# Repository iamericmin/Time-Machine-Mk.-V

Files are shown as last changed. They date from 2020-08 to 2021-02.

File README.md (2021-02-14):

# Time Machine Mk. V
# [Full write-up is on my website! It's also got links to my hackaday page, imgur album, and more goodies. You won't regret it](https://iamericmin.github.io/tm5.html)
Peekaboo!
## DIY nRF52 watch with BLE

Project status: idk

# hi
This is an update of my previous project, the Time Machine Mk. IV. It's better than its predecessor in almost every way I can imagine. There are still some minor bugs and kinks but I am super satisfied with how it turned out. It's got a cyberpunk themed design and motorsport-inspired livery.

# THE JUICY STUFF:
-   PROCESSOR: nRF52832 Soc. 64MHz ARM cortex M4 with 64k RAM and 512k flash.
-   FIRMWARE: Espruino JS interpreter + JS code. I'm working on a C/C++ version.
-   POWER: CR2032 coin cell battery. Guesstimated battery life of around a month.
-   DISPLAY: Dual 7-segment LEDs with five auxiliary LEDs.
-   INPUT: Triple momentary tactile switches.
-   SOUND: Mini piezo speaker.
-   DIMENSIONS: 43.18mm width and length, 9.2mm thickness(1mm thinner than the Mark IV!).
-   STRAP: 22mm NATO strap.

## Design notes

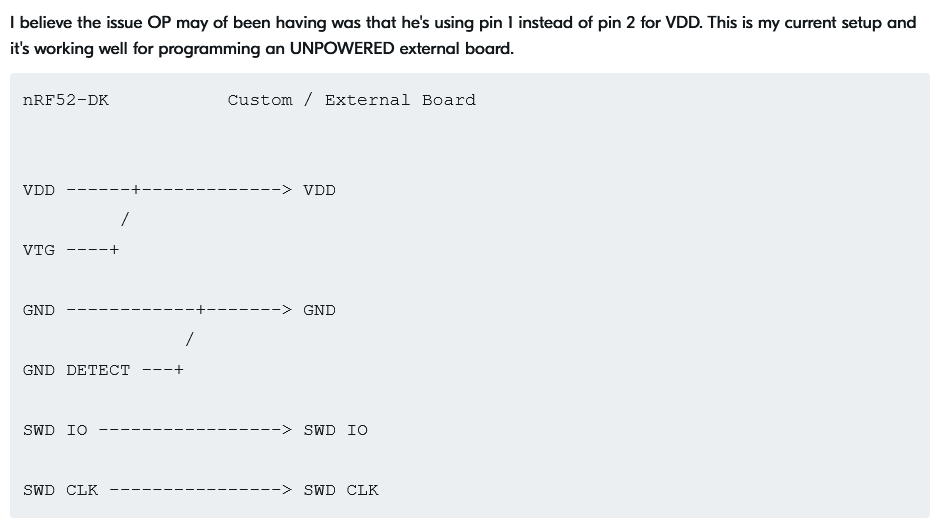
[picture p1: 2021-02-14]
hardware/tm5_swd_connection.png

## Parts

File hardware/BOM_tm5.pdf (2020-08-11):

Description | Quantity Digi-Key Part Number | Unit Price Extended Price Manufacturer
SWITCH TACTILE SPST-NO 0.05A 32V | 3 401-1766-1-ND | 0.49 $1.47 | C&K
LED BLUE CLEAR CHIP SMD | 5 160-1645-1-ND | 0.46 $2.30 | Lite-On Inc.
AUDIO MAGNETIC XDCR 2-4V SMD | 1 668-1060-1-ND | 3.03 $3.03 | PUI Audio, Inc.
RES SMD 220 OHM 1% 1/10W 0603 | 12 311-220HRCT-ND | 0.022 $0.26 | Yageo
CONN HEADER SMD R/A 8POS 1MM | 1 455-1808-1-ND | 0.9 $0.90 | JST Sales America Inc.
CAP CER 22PF 100V C0G/NP0 0603 | 2 399-7874-1-ND | 0.1 $0.20 | KEMET
CRYSTAL 32.7680 KHZ 12.5PF SMD | 1 SER4103CT-ND | 0.41 $0.41 | EPSON
BATTERY RETAINER COIN 20MM SMD | 1 36-3034CT-ND | 0.44 $0.44 | Keystone Electronics
DISPLAY 7SEG 0.28" SGL GRN 10SMD | 2 DSM7TA28105TCT-ND | 2.4 $4.80 | Visual Communications Company - VCC
RX TXRX MOD BLE CHIP SMD | 1 1597-1434-ND | 10.1 $10.10 | Seeed Technology Co., Ltd

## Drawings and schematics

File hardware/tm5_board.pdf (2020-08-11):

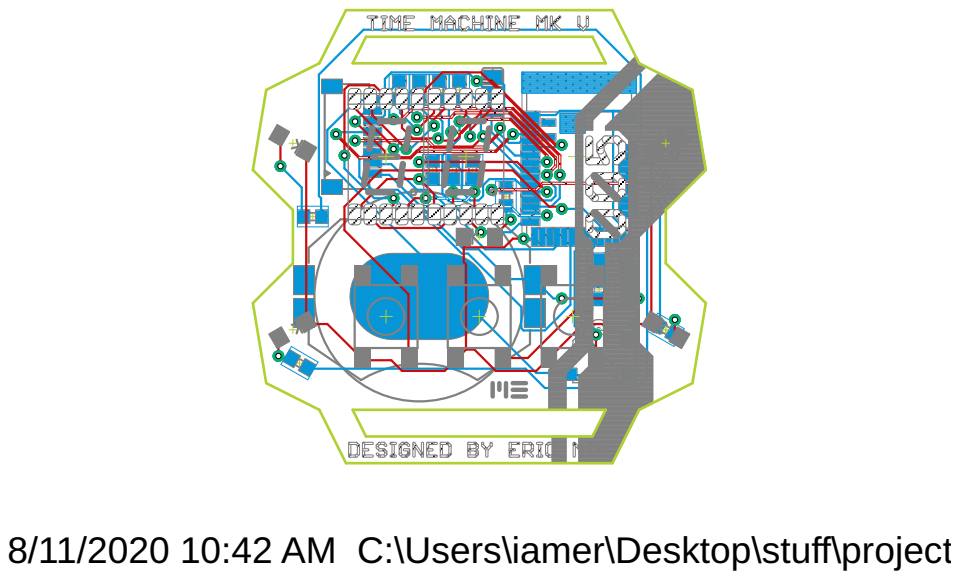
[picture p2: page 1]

8/11/2020 10:42 AM C:\Users\iamer\Desktop\stuff\project

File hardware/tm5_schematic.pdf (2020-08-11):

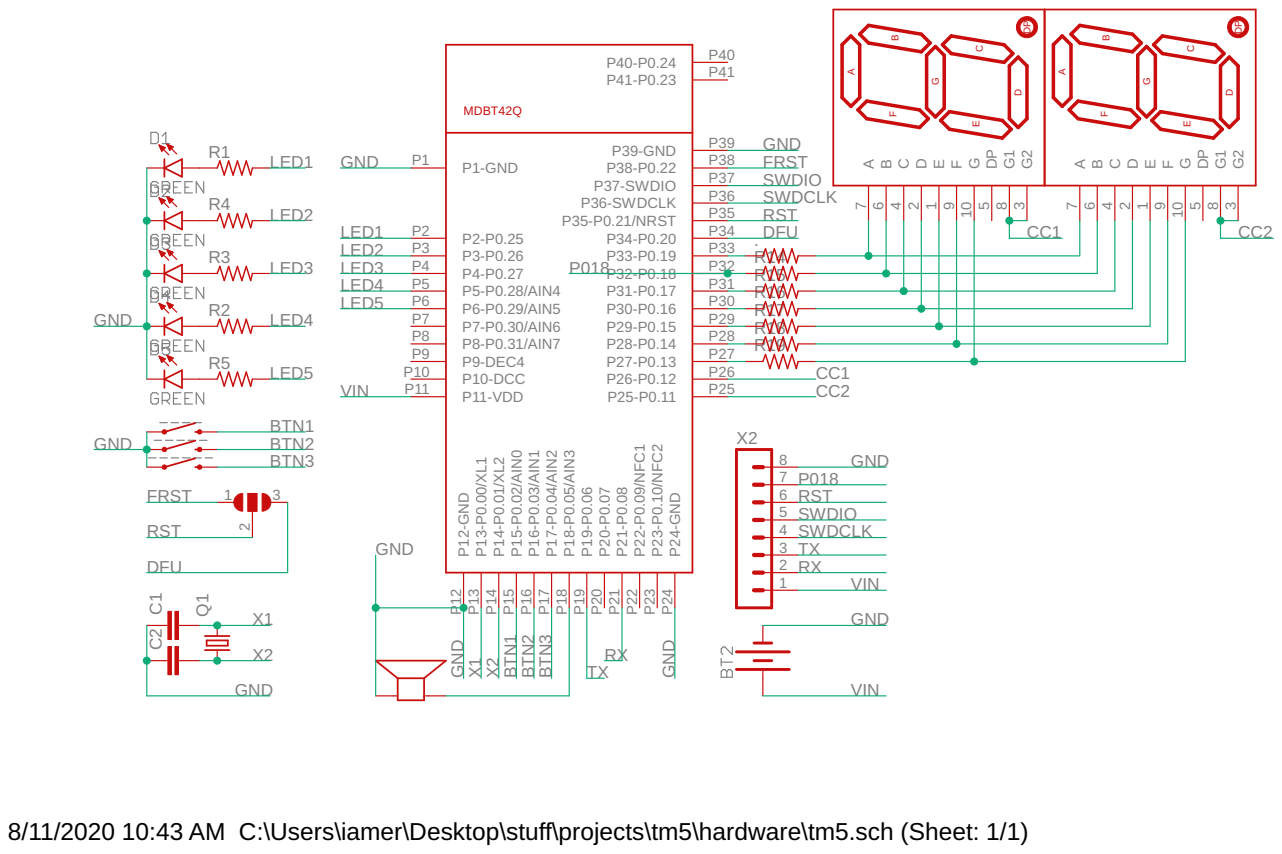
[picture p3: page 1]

8/11/2020 10:43 AM C:\Users\iamer\Desktop\stuff\projects\tm5\hardware\tm5.sch (Sheet: 1/1)

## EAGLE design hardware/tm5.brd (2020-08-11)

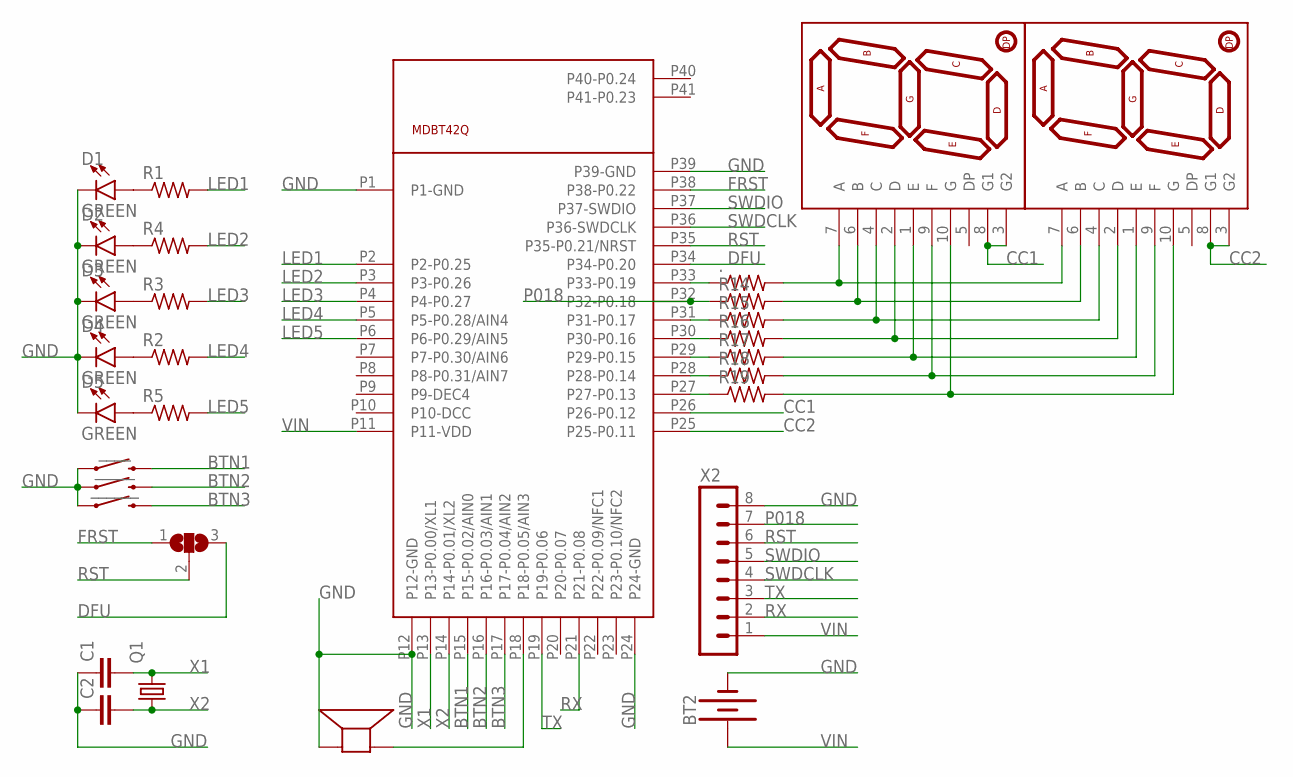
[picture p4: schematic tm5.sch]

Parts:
.: R-US_R0603; R0603
BT2: BATTERY-20MM_SMD_4LEGS_OVERPASTE; BATTCON_20MM_4LEGS_OVERPASTE
C1, C2: C-EUC0603; C0603
CFG: SJ2W; SJ_2
D1, D2, D3, D4, D5: GREEN; LED-1206
Q1: KX-327-NHT; 3.2X1.5
R1, R2, R3, R4, R5, R14, R15, R16, R17, R18, R19: R-US_R0603; R0603
SPK1: SMT-0540-S-R
U$1: MDBT42Q; MDBT40
U$2, U$3: 7-SEGMENT-DISPLAY-1"-RED; 7-SEGMENT-SMD
X2: SM08B-SRSS-TB
____: MOMENTARY-SWITCH-SPST-SMD-6.2MM-TALL; TACTILE_SWITCH_SMD_6.2MM_TALL
_____: MOMENTARY-SWITCH-SPST-SMD-6.2MM-TALL; TACTILE_SWITCH_SMD_6.2MM_TALL
______: MOMENTARY-SWITCH-SPST-SMD-6.2MM-TALL; TACTILE_SWITCH_SMD_6.2MM_TALL

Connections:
BTN1: U$1.P15 (P15-P0.02/AIN0), ____.B2 (2)
BTN2: U$1.P16 (P16-P0.03/AIN1), _____.B2 (2)
BTN3: U$1.P17 (P17-P0.04/AIN2), ______.B2 (2)
CC1: U$1.P26 (P26-P0.12), U$2.3 (G2), U$2.8 (G1)
CC2: U$1.P25 (P25-P0.11), U$3.3 (G2), U$3.8 (G1)
DFU: CFG.3, U$1.P34 (P34-P0.20)
FRST: CFG.1, U$1.P38 (P38-P0.22)
GND: BT2.2 (-), C1.1, C2.1, D1.C, D2.C, D3.C, D4.C, D5.C, SPK1.- (+), U$1.P1 (P1-GND), U$1.P12 (P12-GND), U$1.P24 (P24-GND), U$1.P39 (P39-GND), X2.8, ____.A2 (1), _____.A2 (1), ______.A2 (1)
LED1: R1.2, U$1.P2 (P2-P0.25)
LED2: R4.2, U$1.P3 (P3-P0.26)
LED3: R3.2, U$1.P4 (P4-P0.27)
LED4: R2.2, U$1.P5 (P5-P0.28/AIN4)
LED5: R5.2, U$1.P6 (P6-P0.29/AIN5)
unnamed: ..1, U$1.P33 (P33-P0.19)
unnamed: R15.1, U$1.P31 (P31-P0.17)
unnamed: D1.A, R1.1
unnamed: D2.A, R4.1
unnamed: D3.A, R3.1
unnamed: D4.A, R2.1
unnamed: R16.1, U$1.P30 (P30-P0.16)
unnamed: R17.1, U$1.P29 (P29-P0.15)
unnamed: R18.1, U$1.P28 (P28-P0.14)
unnamed: R19.1, U$1.P27 (P27-P0.13)
unnamed: ..2, U$2.7 (A), U$3.7 (A)
unnamed: SPK1.+ (-), U$1.P18 (P18-P0.05/AIN3)
unnamed: R14.2, U$2.6 (B), U$3.6 (B)
unnamed: R15.2, U$2.4 (C), U$3.4 (C)
unnamed: D5.A, R5.1
unnamed: R16.2, U$2.2 (D), U$3.2 (D)
unnamed: R17.2, U$2.1 (E), U$3.1 (E)
unnamed: R18.2, U$2.9 (F), U$3.9 (F)
unnamed: R19.2, U$2.10 (G), U$3.10 (G)
P018: R14.1, U$1.P32 (P32-P0.18), X2.7
RST: CFG.2, U$1.P35 (P35-P0.21/NRST), X2.6
RX: U$1.P21 (P21-P0.08), X2.2
SWDCLK: U$1.P36 (P36-SWDCLK), X2.4
SWDIO: U$1.P37 (P37-SWDIO), X2.5
TX: U$1.P19 (P19-P0.06), X2.3
VIN: BT2.1 (+), U$1.P11 (P11-VDD), X2.1
X1: C1.2, Q1.2, U$1.P13 (P13-P0.00/XL1)
X2: C2.2, Q1.1, U$1.P14 (P14-P0.01/XL2)

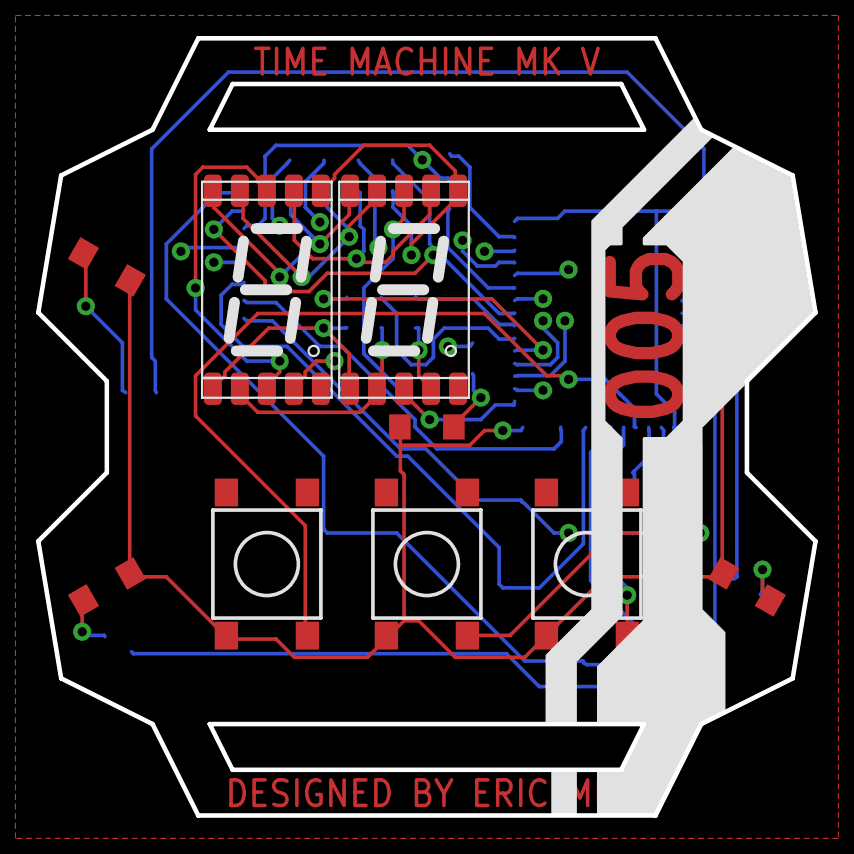
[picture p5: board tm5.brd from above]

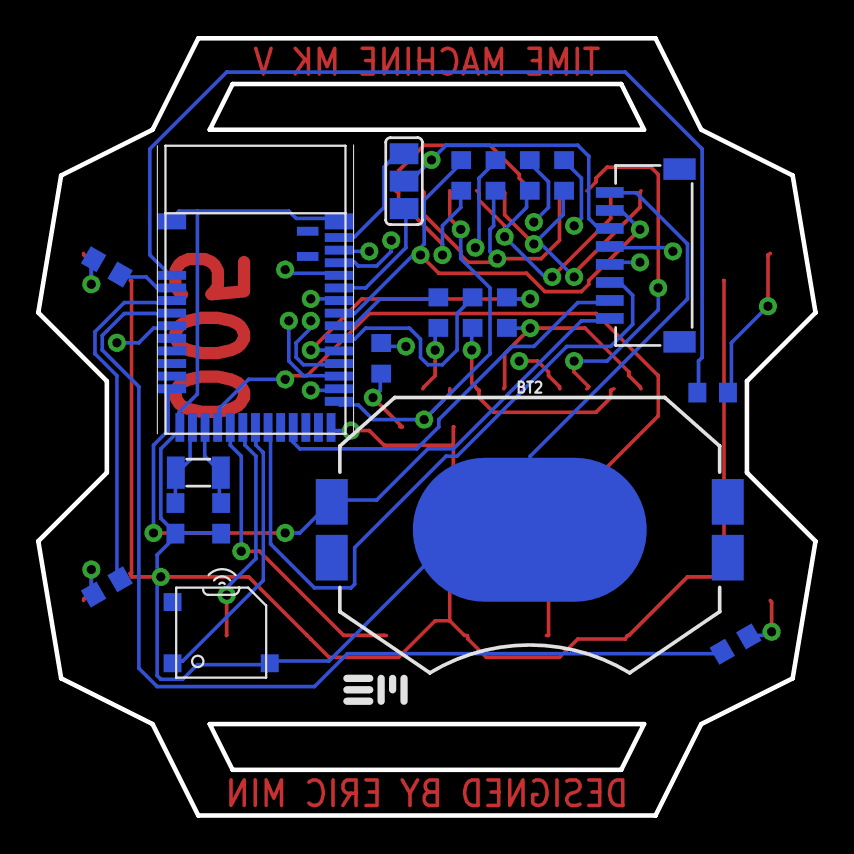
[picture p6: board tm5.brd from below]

Board: 4 copper layers, 43.2 x 43.2 mm, 30 parts (20 on the bottom side), 41 nets.

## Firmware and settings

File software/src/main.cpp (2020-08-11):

/*
 ______   __     __    __     ______        ______     ______   ______   ______     ______     __  __    
/\__  _\ /\ \   /\ "-./  \   /\  ___\      /\  __ \   /\__  _\ /\__  _\ /\  __ \   /\  ___\   /\ \/ /    
\/_/\ \/ \ \ \  \ \ \-./\ \  \ \  __\      \ \  __ \  \/_/\ \/ \/_/\ \/ \ \  __ \  \ \ \____  \ \  _"-.  
   \ \_\  \ \_\  \ \_\ \ \_\  \ \_____\     \ \_\ \_\    \ \_\    \ \_\  \ \_\ \_\  \ \_____\  \ \_\ \_\ 
    \/_/   \/_/   \/_/  \/_/   \/_____/      \/_/\/_/     \/_/     \/_/   \/_/\/_/   \/_____/   \/_/\/_/ 
2020 Eric Min

*/

#include <Arduino.h>

int dg1 = 12;
int dg2 = 11;
int A = 19;
int B = 18;
int C = 17;
int D = 16;
int E = 15;
int F = 14;
int G = 13;
int l1 = 25;
int l2 = 26;
int l3 = 27;
int l4 = 28;
int l5 = 29;
int left = 0;
int slct = 1;
int right = 2;
int spk = 5;

/*
A little help?
            ----A----
            |       |
            F       B
            |       |
            ----G----
            |       |
            E       C
            |       |
            ----D----
*/

int seg[7] = {A, B, C, D, E, F};
int leds[12] = {A, B, C, D, E, F, l1, l2, l3, l4, l5};

int one[8] = {F, E};
int two[8] = {A, B, G, E, D};
int three[8] = {A, B, G, C, D};
int four[8] = {F, G, B, C};
int five[8] = {A, F, G, C, D};
int six[8] = {A, F, E, D, C, G};
int seven[8] = {F, A, B, C};
int eight[8] = {A, B, C, D, E, F, G};
int nine[8] = {F, A, B, G, C, D};
int zero[8] = {A, B, C, D, E, F};
int aa[8] = {E, F, A, B, C ,G};
int bb[8] = {F, E, D, C ,G};
int cc[8] = {A, F, E, D};
int dd[8] = {B, C, D, E, G};
int ee[8] = {A, F, G, E, D};
int ff[8] = {A, F, G, E};

void write(int ledBuffer[8]) {
  for (int i=0; i<8; i++) {
    digitalWrite(ledBuffer[i], 1);
  }
}

void unWrite(int ledBuffer[8]) {
  for (int i=0; i<8; i++) {
    digitalWrite(ledBuffer[i], 0);
  }
}

void allClear() {
	digitalWrite(dg1, 1);
	digitalWrite(dg2, 1);
	for (unsigned int i=0; i<sizeof(leds); i++) {
		digitalWrite(leds[i], 0);
	}
}

void clearDigits() {
	for (unsigned int i=0; i<sizeof(seg); i++) {
		digitalWrite(seg[i], 0);
	}
}

void display(int digit, int buf[8]) {
  allClear();
  if (digit == 1) {
    digitalWrite(dg1, 0);
    digitalWrite(dg2, 1);
  }

  if (digit == 2) {
    digitalWrite(dg2, 0);
    digitalWrite(dg1, 1);
  }

  if (digit == 3) {
    digitalWrite(dg1, 0);
    digitalWrite(dg2, 0);
  }

  clearDigits();
  write(buf);
}

void showDisp(int buf1[8], int buf2[8]) {
    display(1, buf1);
    display(2, buf2);
}

void setup() {
	pinMode(17, OUTPUT);
}

int segs[6] = {E, F, A, B, C, D};
void loop() {
	allClear();
	digitalWrite(dg1, 1);
	digitalWrite(dg2, 1);
	for (int i=0; i<6; i++) {
		digitalWrite(segs[i], 1);
		delay(50);
	}
}

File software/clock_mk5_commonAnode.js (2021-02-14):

/*

    
    ###  ###  ###   _______                   __  ___           __    _                ###  ###  ###
   ###  ###  ###   /_  __(_)___ ___  ___     /  |/  /___ ______/ /_  (_)___  ___      ###  ###  ###
  ###  ###  ###     / / / / __ `__ \/ _ \   / /|_/ / __ `/ ___/ __ \/ / __ \/ _ \    ###  ###  ###
 ###  ###  ###     / / / / / / / / /  __/  / /  / / /_/ / /__/ / / / / / / /  __/   ###  ###  ###
###  ###  ###     /_/ /_/_/ /_/ /_/\___/  /_/  /_/\__,_/\___/_/ /_/_/_/ /_/\___/   ###  ###  ###

Digital watch made by Eric Min
Based on Espruino firmware by Gordon Williams

*/

var dg1 = D12;
var dg2 = D11;
var A = D19;
var B = D18;
var C = D17;
var D = D16;
var E = D15;
var F = D14;
var G = D13;
var l1 = D25;
var l2 = D26;
var l3 = D27;
var l4 = D28;
var l5 = D29;
var left = D2;
var select = D3;
var right = D4;
var spk = D5;

pinMode(dg1, "output");
pinMode(dg2, "output");
pinMode(A, "output");
pinMode(B, "output");
pinMode(C, "output");
pinMode(D, "output");
pinMode(E, "output");
pinMode(F, "output");
pinMode(G, "output");
pinMode(l1, "output");
pinMode(l2, "output");
pinMode(l3, "output");
pinMode(l4, "output");
pinMode(l5, "output");
pinMode(spk, "output");

digitalWrite(dg1, 1);
digitalWrite(dg1, 1);

function allClear() {
  digitalWrite(A, 0);
  digitalWrite(B, 0);
  digitalWrite(C, 0);
  digitalWrite(D, 0);
  digitalWrite(E, 0);
  digitalWrite(F, 0);
  digitalWrite(G, 0);
  digitalWrite(l1, 0);
  digitalWrite(l2, 0);
  digitalWrite(l3, 0);
  digitalWrite(l4, 0);
  digitalWrite(l5, 0);
}

function clearDigits() {
  digitalWrite(A, 0);
  digitalWrite(B, 0);
  digitalWrite(C, 0);
  digitalWrite(D, 0);
  digitalWrite(E, 0);
  digitalWrite(F, 0);
  digitalWrite(G, 0);
}

function freq(f) { 
  if (f===0) digitalWrite(spk,0);
  else analogWrite(spk, 0.5, { freq: f } );
}

/*
A little help?

            ----A----
            |       |
            F       B
            |       |
            ----G----
            |       |
            E       C
            |       |
            ----D----
*/

function one() {
  digitalWrite(F, 1);
  digitalWrite(E, 1);
}

function two() {
  digitalWrite(A, 1);
  digitalWrite(B, 1);
  digitalWrite(G, 1);
  digitalWrite(E, 1);
  digitalWrite(D, 1);
}

function three() {
  digitalWrite(A, 1);
  digitalWrite(B, 1);
  digitalWrite(G, 1);
  digitalWrite(C, 1);
  digitalWrite(D, 1);
}

function four() {
  digitalWrite(F, 1);
  digitalWrite(G, 1);
  digitalWrite(B, 1);
  digitalWrite(C, 1);
}

function five() {
  digitalWrite(A, 1);
  digitalWrite(F, 1);
  digitalWrite(G, 1);
  digitalWrite(C, 1);
  digitalWrite(D, 1);
}

function six() {
  digitalWrite(A, 1);
  digitalWrite(F, 1);
  digitalWrite(E, 1);
  digitalWrite(G, 1);
  digitalWrite(C, 1);
  digitalWrite(D, 1);
}

function seven() {
  digitalWrite(F, 1);
  digitalWrite(A, 1);
  digitalWrite(B, 1);
  digitalWrite(C, 1);
}

function eight() {
  digitalWrite(A, 1);
  digitalWrite(B, 1);
  digitalWrite(C, 1);
  digitalWrite(D, 1);
  digitalWrite(E, 1);
  digitalWrite(F, 1);
  digitalWrite(G, 1);
}

function nine() {
  digitalWrite(A, 1);
  digitalWrite(B, 1);
  digitalWrite(C, 1);
  digitalWrite(G, 1);
  digitalWrite(F, 1);
  digitalWrite(D, 1);
}

function zero() {
  digitalWrite(A, 1);
  digitalWrite(B, 1);
  digitalWrite(C, 1);
  digitalWrite(D, 1);
  digitalWrite(E, 1);
  digitalWrite(F, 1);
}

function aa() {
  digitalWrite(A, 1);
  digitalWrite(B, 1);
  digitalWrite(C, 1);
  digitalWrite(E, 1);
  digitalWrite(F, 1);
  digitalWrite(G, 1);
}

function bb() {
  digitalWrite(C, 1);
  digitalWrite(D, 1);
  digitalWrite(E, 1);
  digitalWrite(F, 1);
  digitalWrite(G, 1);
}

function cc() {
  digitalWrite(A, 1);
  digitalWrite(F, 1);
  digitalWrite(E, 1);
  digitalWrite(D, 1);

}

function dd() {
  digitalWrite(B, 1);
  digitalWrite(C, 1);
  digitalWrite(G, 1);
  digitalWrite(E, 1);
  digitalWrite(D, 1);
}

function ee() {
  digitalWrite(A, 1);
  digitalWrite(F, 1);
  digitalWrite(G, 1);
  digitalWrite(E, 1);
  digitalWrite(D, 1);
}

function ff() {
  digitalWrite(A, 1);
  digitalWrite(F, 1);
  digitalWrite(G, 1);
  digitalWrite(E, 1);
}

function gg() {
  digitalWrite(A, 1);
  digitalWrite(F, 1);
  digitalWrite(E, 1);
  digitalWrite(D, 1);
  digitalWrite(C, 1);
}

function hh() {
  digitalWrite(F, 1);
  digitalWrite(E, 1);
  digitalWrite(G, 1);
  digitalWrite(C, 1);
  digitalWrite(B, 1);
}

function ii() {
  digitalWrite(B, 1);
  digitalWrite(C, 1);
}

function jj() {
  digitalWrite(B, 1);
  digitalWrite(C, 1);
  digitalWrite(E, 1);
  digitalWrite(D, 1);
}

function pp() {
  digitalWrite(A, 1);
  digitalWrite(F, 1);
  digitalWrite(E, 1);
  digitalWrite(G, 1);
  digitalWrite(B, 1);
}

function rr() {
  digitalWrite(G, 1);
  digitalWrite(E, 1);
}

function ss() {
  five();
}

function tt() {
  digitalWrite(D, 1);
  digitalWrite(F, 1);
  digitalWrite(E, 1);
  digitalWrite(G, 1);
}

function ll() {
  digitalWrite(D, 1);
  digitalWrite(F, 1);
  digitalWrite(E, 1);
}

function nn() {
  digitalWrite(D, 1);
  digitalWrite(F, 1);
  digitalWrite(G, 1);
}

function uu() {
  digitalWrite(D, 1);
  digitalWrite(F, 1);
  digitalWrite(E, 1);
}

function space() {
  digitalWrite(A, 0);
  digitalWrite(B, 0);
  digitalWrite(C, 0);
  digitalWrite(D, 0);
  digitalWrite(E, 0);
  digitalWrite(F, 0);
  digitalWrite(G, 0);
}

/*
function menu() {
  itemNum = 3;
  while(digitalRead(select) !== 1) {
    if (digitalRead(right, 1) === 0) {
      itemNum += 1;
    }
    if (itemNum == 4){ itemNum = 1;}
    else if (itemNum == 1) {
      showDisp("p", "r", BTN, 0);
    }
    else if (itemNum == 2) {
      showDisp("s", "t", BTN, 0);
    }
    else if (itemNum == 3) {
      showDisp("a", "l", BTN, 0);
    }
  }
}
*/

function data() {
  time = new Date();
  month = time.getMonth();
  date = time.getDate();
  hour = time.getHours();
  if (hour > 12) {
    hour = hour - 12;
  }
  if (hour === 0) {
    hour = 12;
  }
  hourFirstDigit = hour.toString()[0];
  hourSecondDigit = hour.toString()[1];
  min = time.getMinutes();
  minFirstDigit = min.toString()[0];
  minSecondDigit = min.toString()[1];
}
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

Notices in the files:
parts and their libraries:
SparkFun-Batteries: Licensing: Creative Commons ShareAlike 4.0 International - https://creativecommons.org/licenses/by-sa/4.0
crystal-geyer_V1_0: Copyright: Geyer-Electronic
